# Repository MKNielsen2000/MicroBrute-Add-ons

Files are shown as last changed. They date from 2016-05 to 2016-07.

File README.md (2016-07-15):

#Microbrute addon boards / hacks
---

A bunch of boards for hacking / modifying the MicroBrute:
* White Noise Add-on
* Buffered output add-on

**DISCLAIMER: These hacks/modifications are potentially dangerous for you and/or your synth. They are only for people with advanced electronics skills. I will not take any responsibility for any damage to your synth or yourself and understand that once you open your MicroBrute you lose your warranty.**

## White Noise Add-on
A tiny board that adds white noise to the Microbrute. 

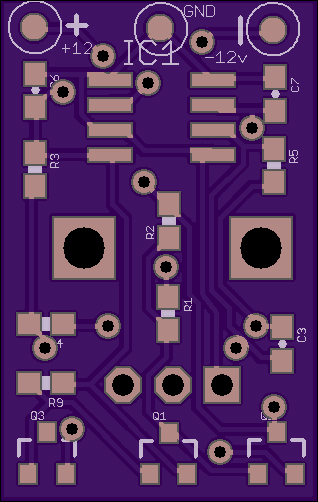
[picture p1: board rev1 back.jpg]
Back of board rev 1

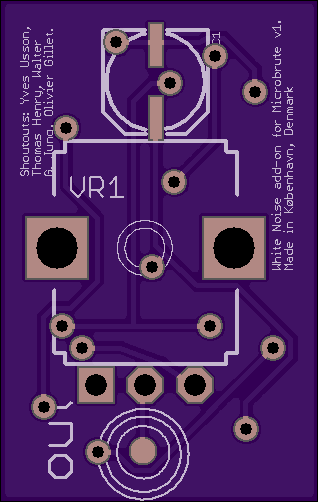
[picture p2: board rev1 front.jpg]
Front of board rev 1


Does what it says on the tin.

Based on a circuit from [Thomas Henry's noise generator cookbook](http://www.magsmoke.com/thomas_henry_books.asp).

Made possible thanks to [Yves Usson's publishing of all schematics related to the Microbrute.](http://hackabrute.yusynth.net/index_en.php)

#####STATUS
Boards done, need testing. 

####Connections

Power:
* Connect +12v to tp70 on the Microbrute
* Connect -12v to tp71 on the Microbrute
* Connect GND to tp72 on the Microbrute

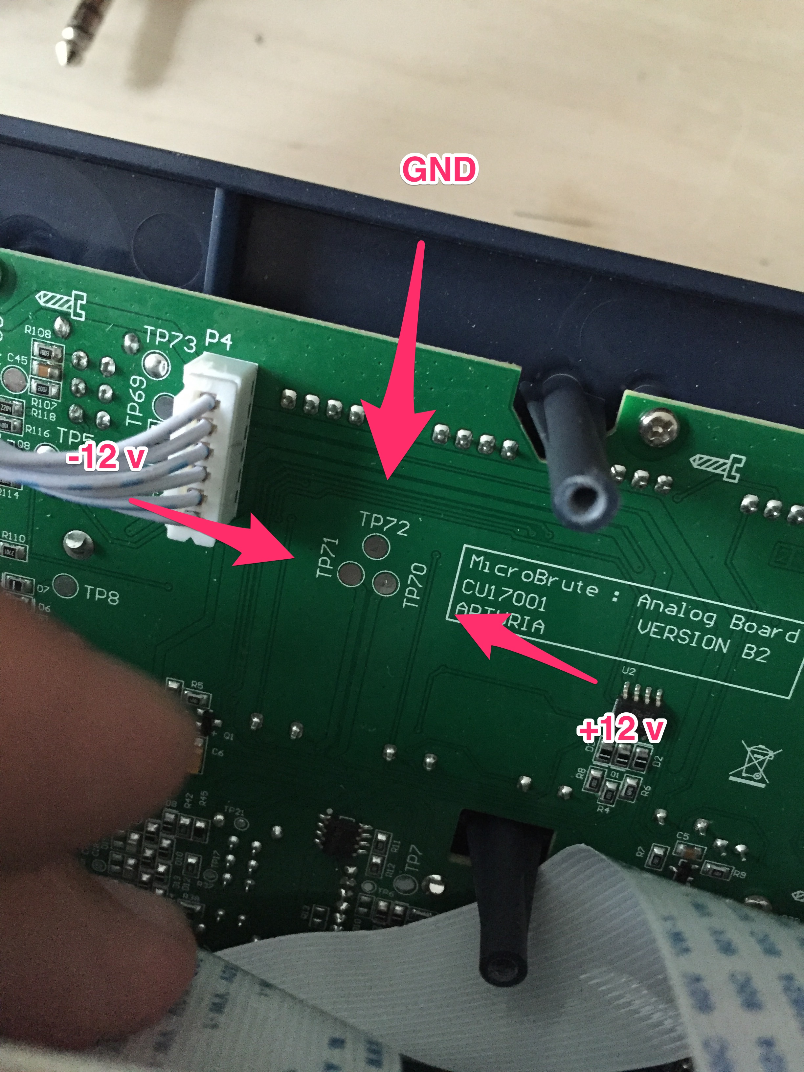
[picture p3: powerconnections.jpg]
power connections


White noise:
* Connect OUT on white noise board to tp47 (external audio in) on the Microbrute

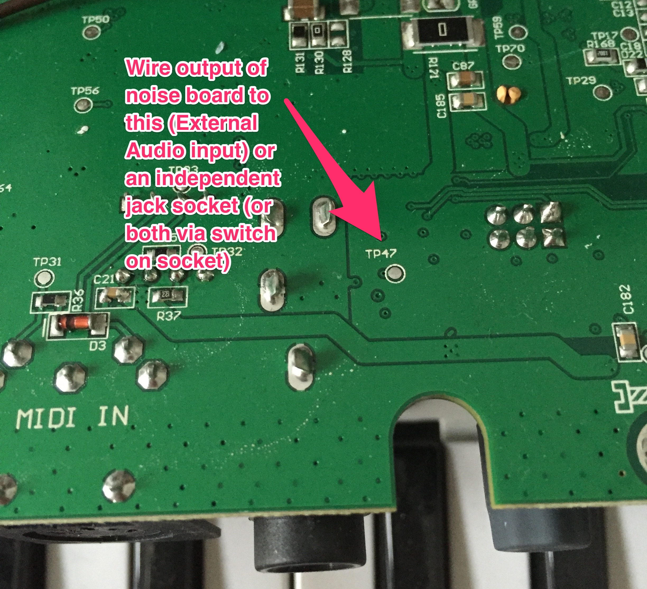
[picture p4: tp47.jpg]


## Buffered output Add-on
There are four waveform output hacks possible on the Microbrute but I've always thought it a damn shame that they get wired directly to output jacks with no protection and buffering which causes all sorts of issues. This boards fixes that problem. You mount this on one of the output jacks and wire three others to this board including the four waveforms. You can either pull the power from the above mentioned test points or daisy chain the power with the white noise generator. Pretty suave. 

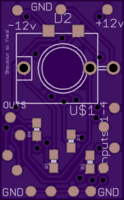
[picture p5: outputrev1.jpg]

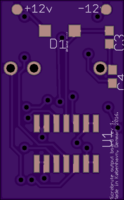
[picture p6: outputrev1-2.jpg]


#####STATUS
Boards done, need testing.

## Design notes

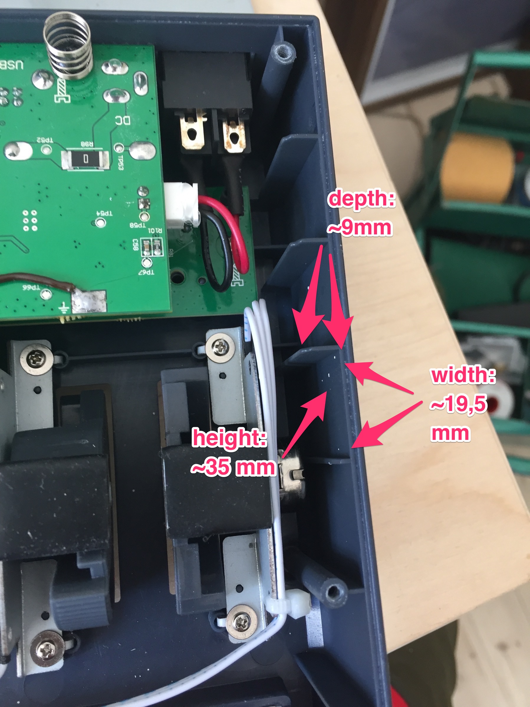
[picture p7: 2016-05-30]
Inner dimensions microbrute.jpg

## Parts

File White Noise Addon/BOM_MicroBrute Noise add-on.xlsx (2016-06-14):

Part | Value | Package | Description | PROD_ID | VALUE | Mouser
C1 | 10uf | PANASONIC_C | Capacitor Polarized |  |  | 667-EEE-FP1E100AR
C3 | 10pF | 0603-CAP | CAP-00810 | CAP-00810 |  | 81-GRM1885C1H102FA1J
C6 | 0.1uF | 0603-CAP | CAP-00810 | CAP-00810 | 0.1uF | 81-GRM188R61C104KA1D
C7 | 0.1uF | 0603-CAP | CAP-00810 | CAP-00810 | 0.1uF | 81-GRM188R61C104KA1D
IC1 | TL071D | SO08 | OP AMP |  |  | 511-TL071CDT
Q1 | mmbt3904 | SOT23-3 | Generic NPN BJT | TRANS-08049 |  | 863-MMBT3904LT1G
Q2 | mmbt3904 | SOT23-3 | Generic NPN BJT | TRANS-08049 |  | 863-MMBT3904LT1G
Q3 | mmbt3904 | SOT23-3 | Generic NPN BJT | TRANS-08049 |  | 863-MMBT3904LT1G
R1 | 47k | 0603-RES | Resistor |  |  | 667-ERJ-3EKF4702V
R2 | 10k | 0603-RES | Resistor |  |  | 667-ERJ3EKF1002V
R3 | 2.2k | 0603-RES | Resistor |  |  | 667-ERJ-3EKF2201V
R4 | 100k | 0603-RES | Resistor |  |  | 667-ERJ3EKF1003V
R5 | 100k | 0603-RES | Resistor |  |  | 667-ERJ3EKF1003V
R9 | 180k | 0603-RES | Resistor |  |  | 667-ERJ-3EKF1803V
VR1 | 100k | 9MM_SNAP-IN_POT | 9mm vertical snap-in pot, Alpha / Panasonic style |  |  | Buy at Thonk or Tayda
D1, D2 | Schottky diode PMEG2010AEB | SOD523 |  |  |  | 771-PMEG2010AEBT/R

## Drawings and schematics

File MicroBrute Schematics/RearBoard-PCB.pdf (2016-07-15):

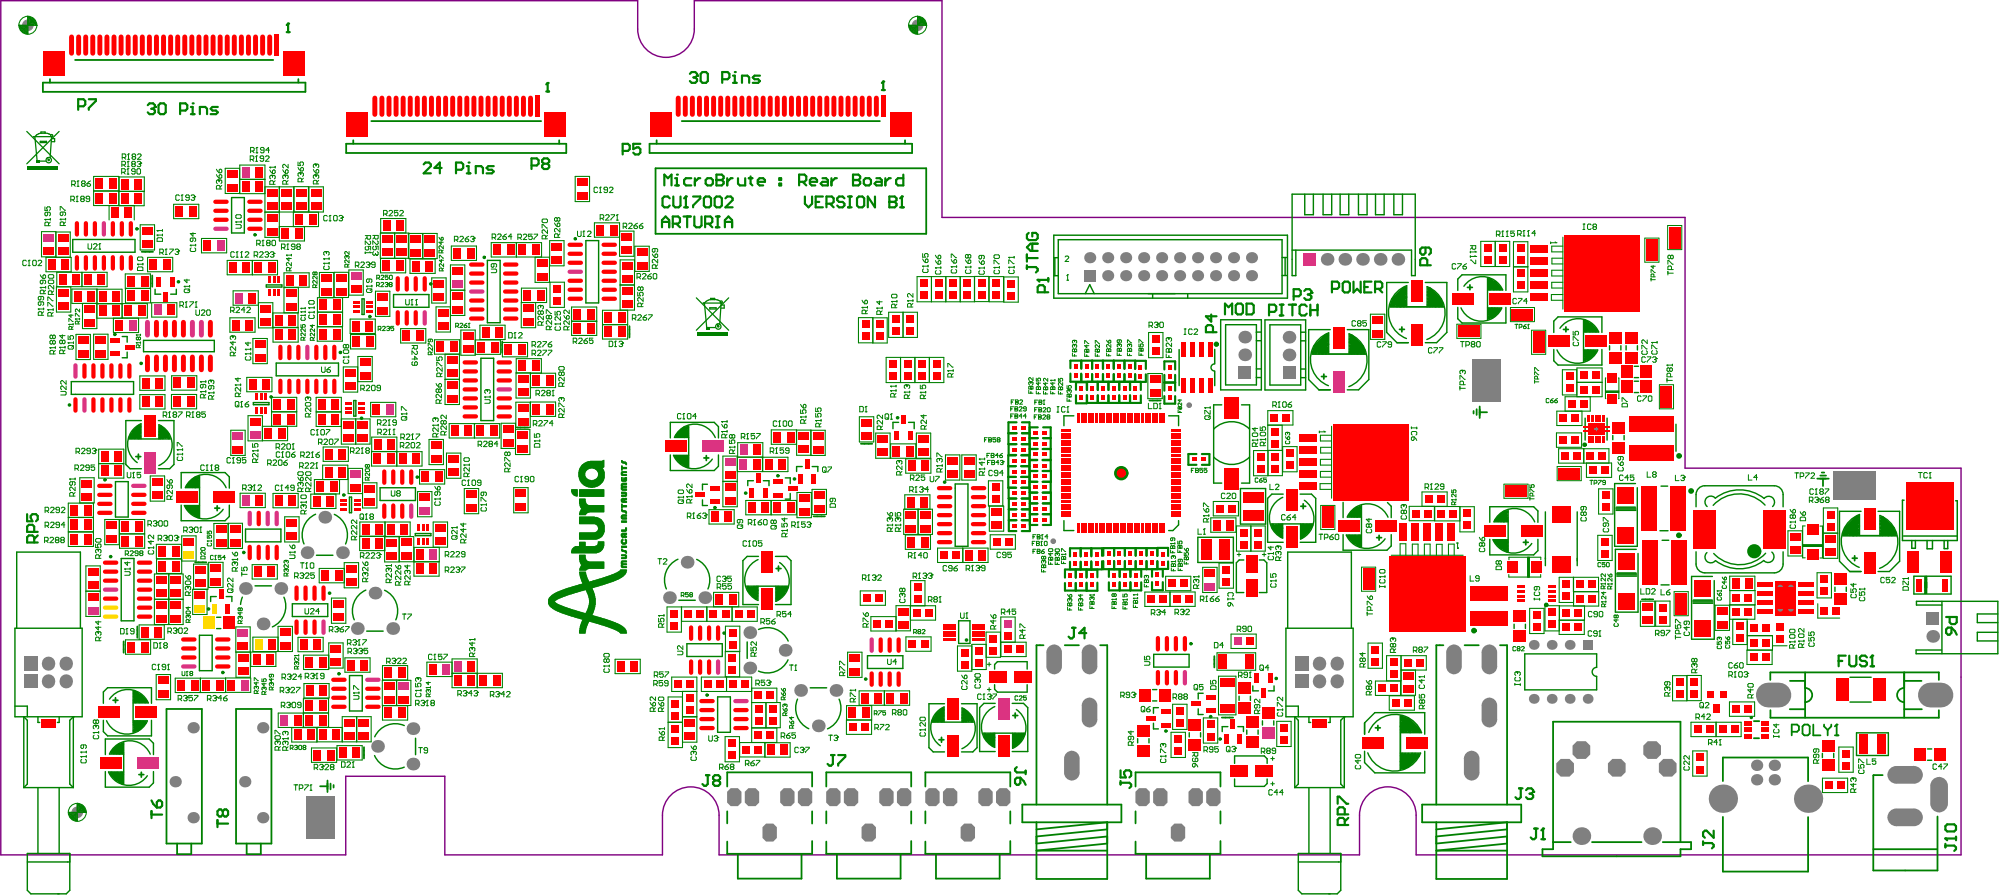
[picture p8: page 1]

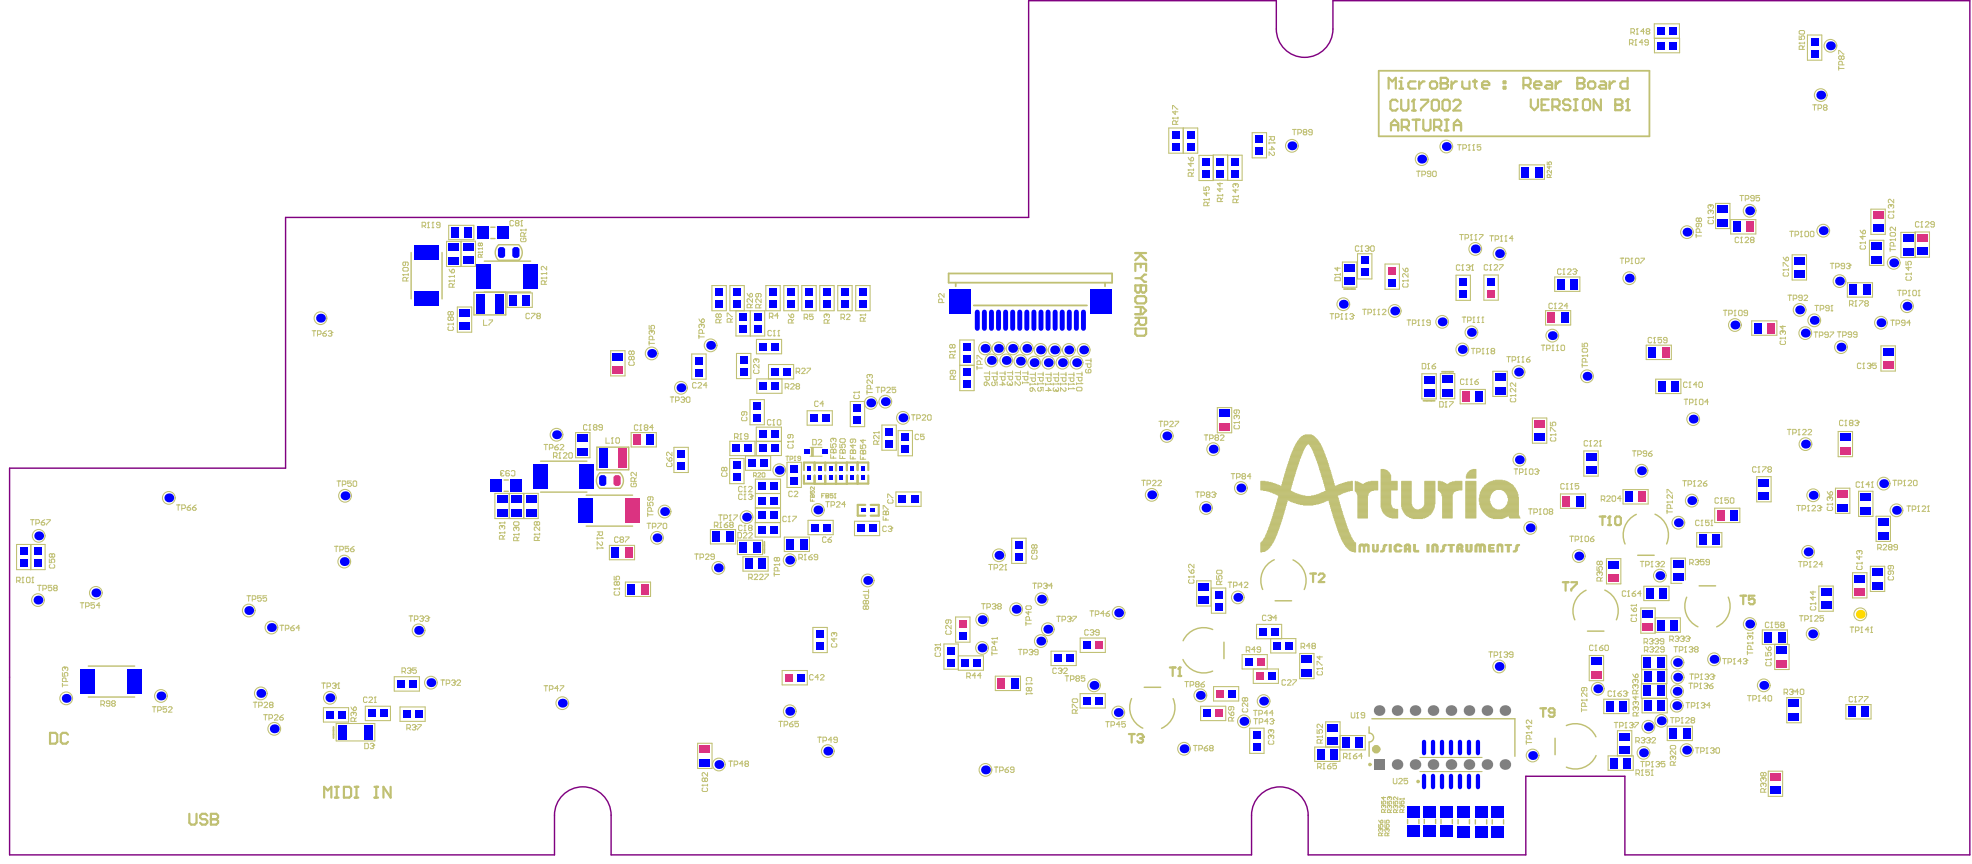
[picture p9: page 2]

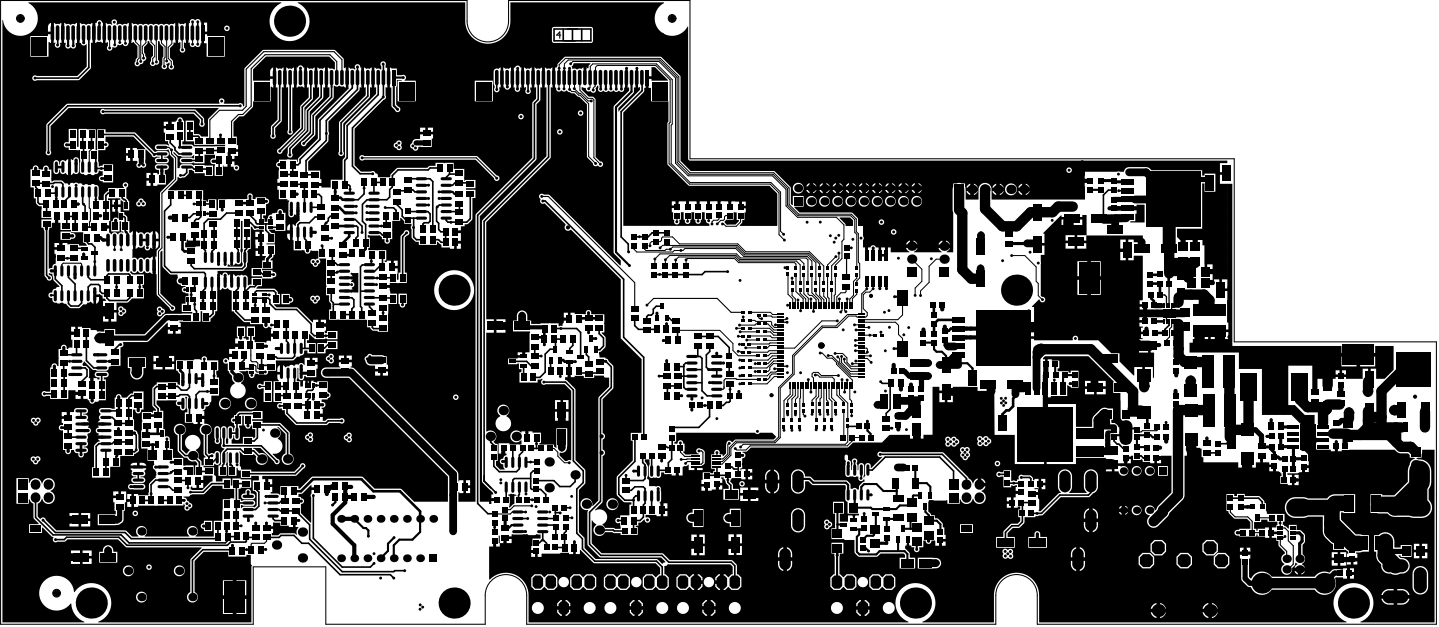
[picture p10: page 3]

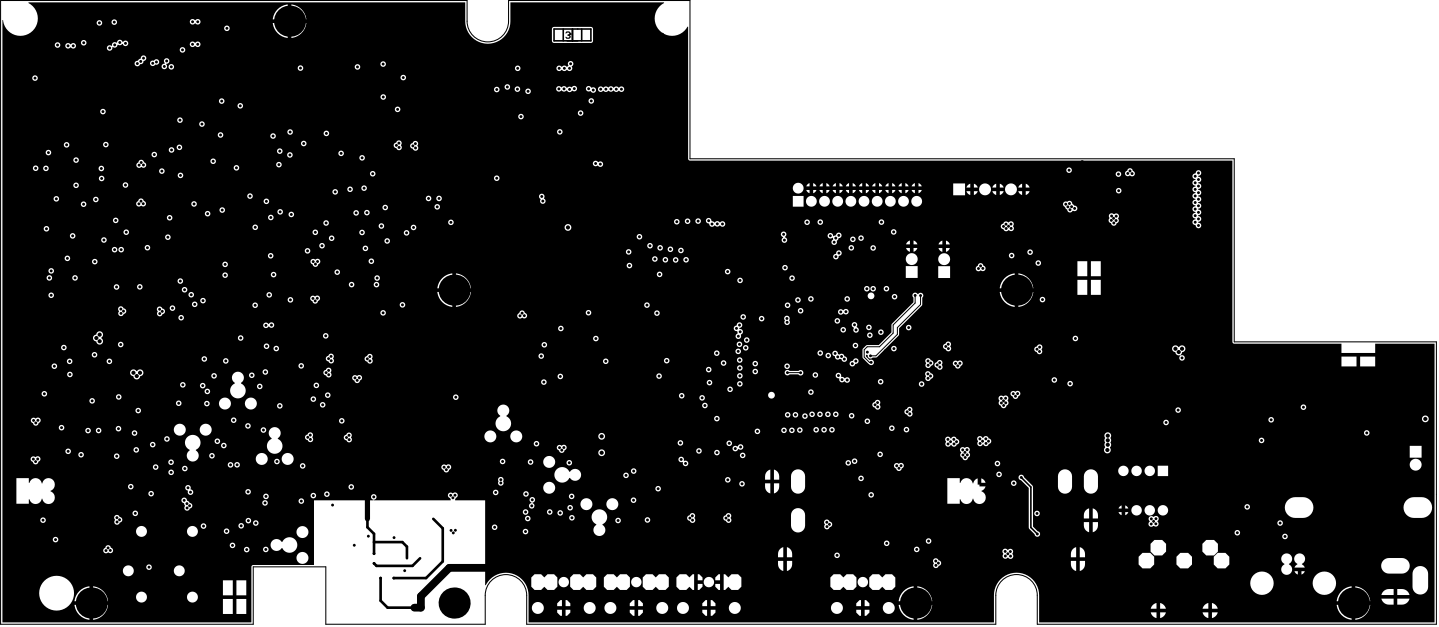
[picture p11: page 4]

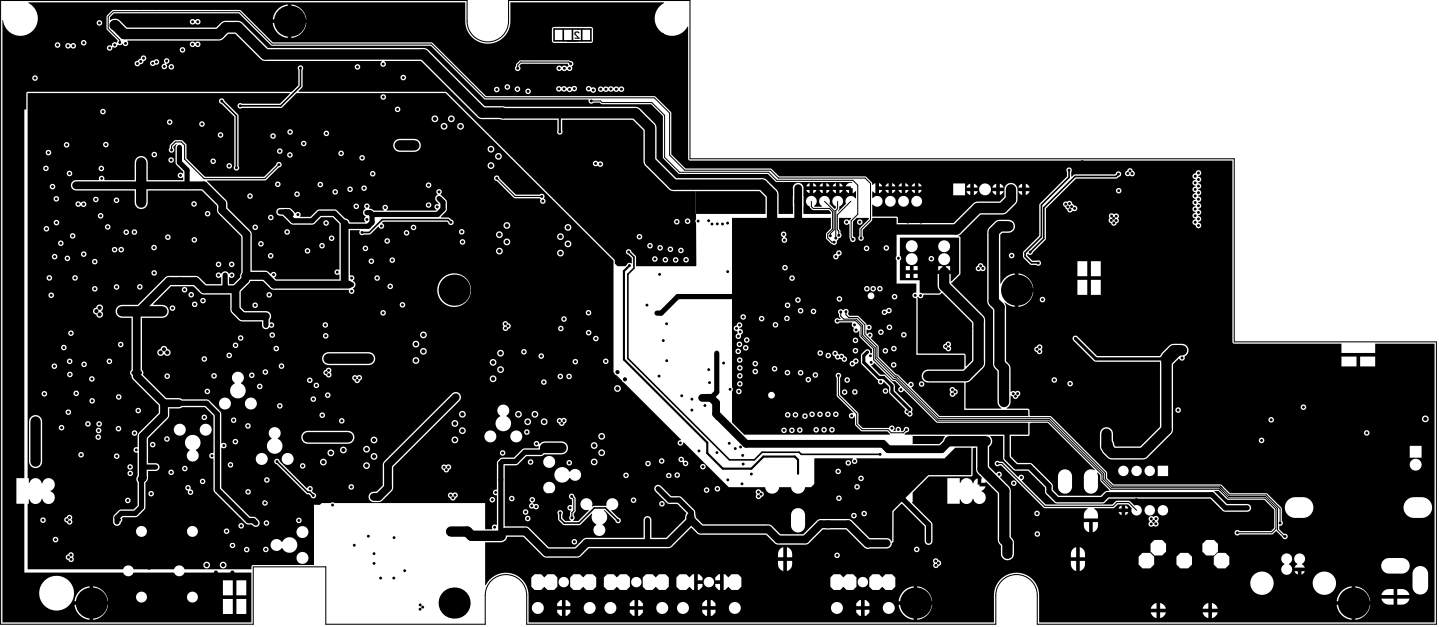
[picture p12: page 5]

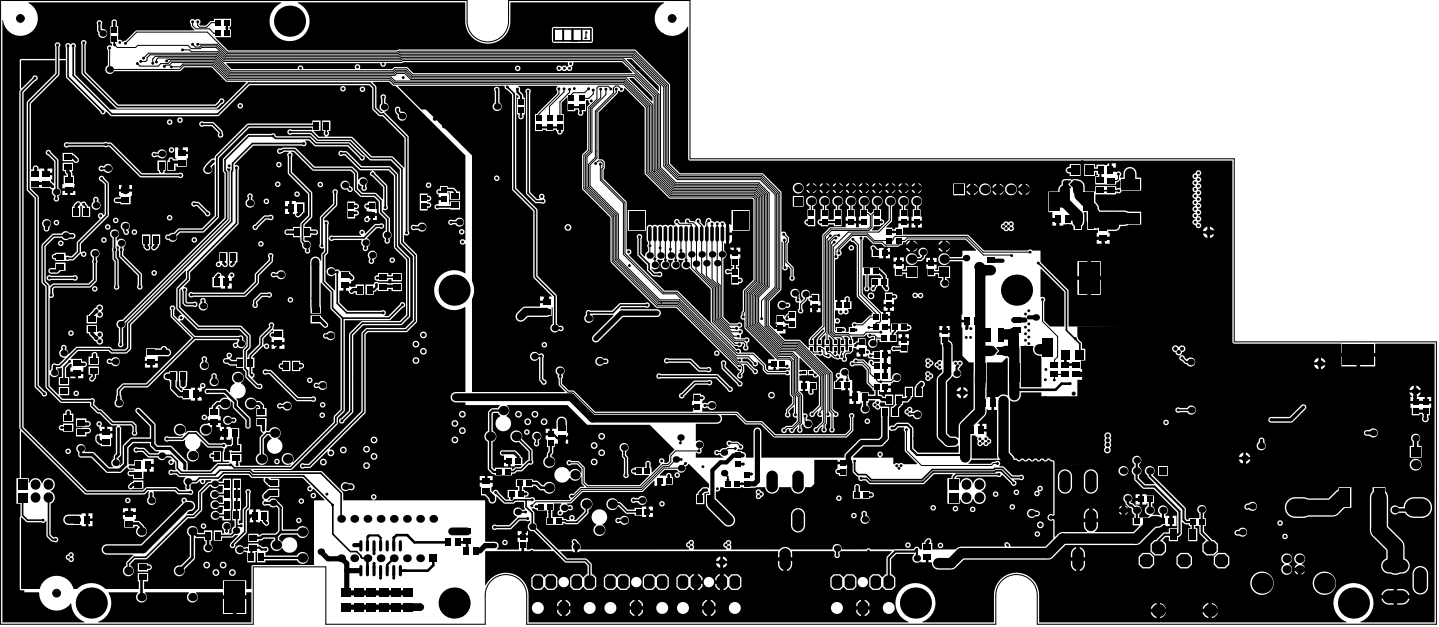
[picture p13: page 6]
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

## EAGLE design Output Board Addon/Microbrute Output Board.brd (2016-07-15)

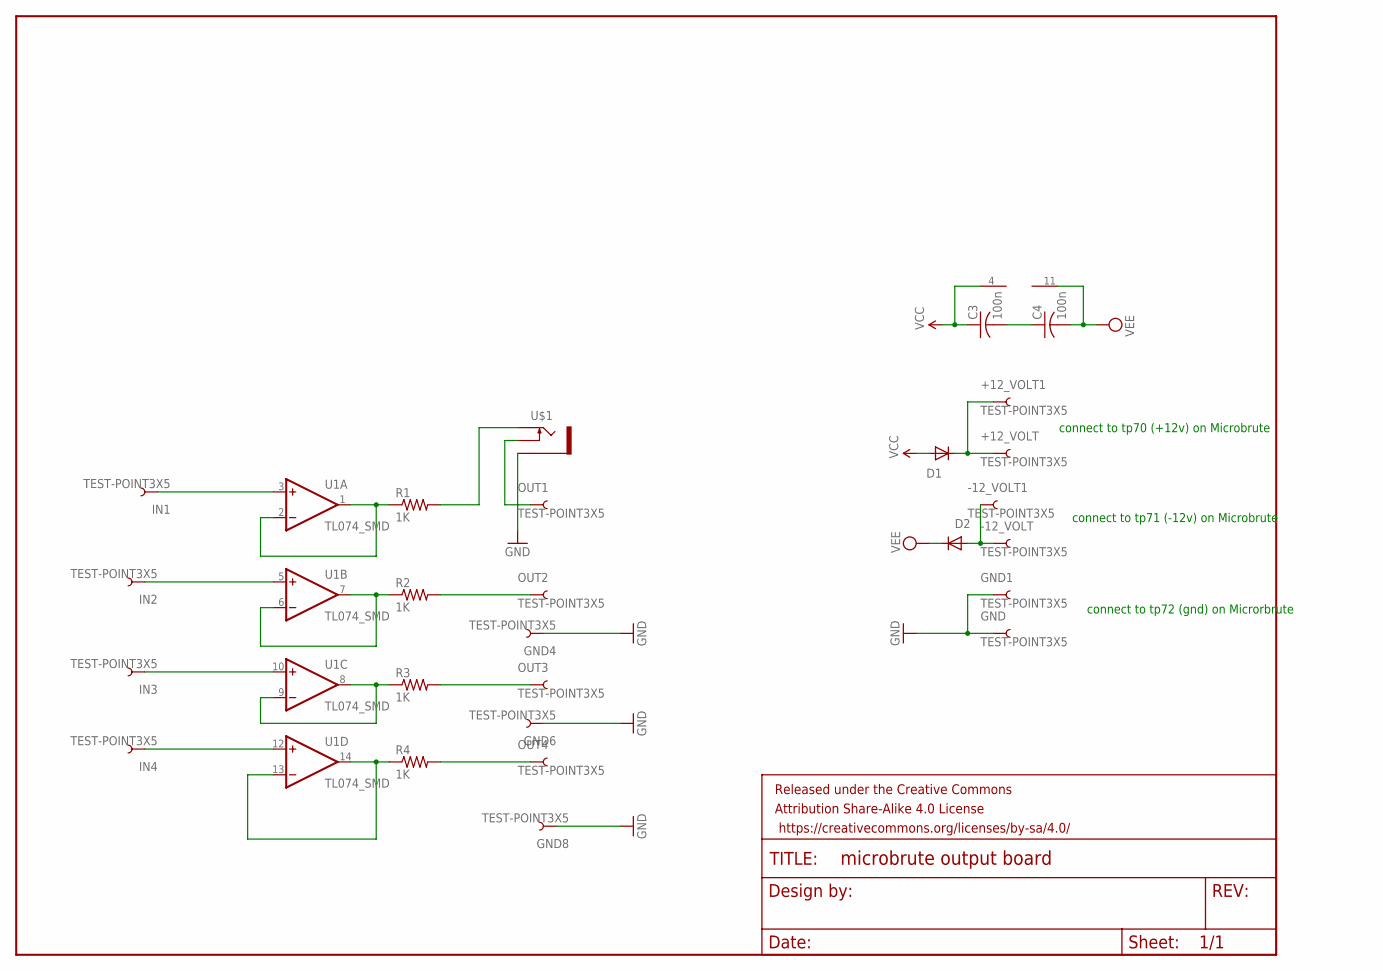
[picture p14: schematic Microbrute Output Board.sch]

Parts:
+12_VOLT, +12_VOLT1: TEST-POINT3X5; PAD.03X.05
-12_VOLT, -12_VOLT1: TEST-POINT3X5; PAD.03X.05
C3, C4: 100n; C0603
D1, D2: 1N5819HW; SOD123
FRAME1: FRAME-LETTER; CREATIVE_COMMONS
GND, GND1, GND4, GND6, GND8: TEST-POINT3X5; PAD.03X.05
IN1, IN2, IN3, IN4: TEST-POINT3X5; PAD.03X.05
OUT1, OUT2, OUT3, OUT4: TEST-POINT3X5; PAD.03X.05
R1, R2, R3, R4: 1K; 0603-RES
U1: TL074_SMD; SO14
U$1: THONKICONNNEW; WQP-PJ301M-12_JACK

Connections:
GND: GND.P$1, GND1.P$1, GND4.P$1, GND6.P$1, GND8.P$1, U$1.P$3_SLEEVE (SLEEVE)
GND1: C3.2, C4.1
unnamed: +12_VOLT.P$1, +12_VOLT1.P$1, D1.C
unnamed: -12_VOLT.P$1, -12_VOLT1.P$1, D2.A
unnamed: R1.2, U$1.P$1_TIP (TIP)
unnamed: OUT1.P$1, U$1.P$2_SWITCH (SWITCH)
unnamed: OUT2.P$1, R2.2
unnamed: R3.1, U1.8 (OUT), U1.9 (-IN)
unnamed: OUT4.P$1, R4.2
unnamed: R1.1, U1.1 (OUT), U1.2 (-IN)
unnamed: R2.1, U1.6 (-IN), U1.7 (OUT)
unnamed: OUT3.P$1, R3.2
unnamed: R4.1, U1.13 (-IN), U1.14 (OUT)
unnamed: IN2.P$1, U1.5 (+IN)
unnamed: IN3.P$1, U1.10 (+IN)
unnamed: IN4.P$1, U1.12 (+IN)
unnamed: IN1.P$1, U1.3 (+IN)
VCC: C3.1, D1.A, U1.4 (V+)
VEE: C4.2, D2.C, U1.11 (V-)

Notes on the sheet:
connect to tp70 (+12v) on Microbrute
connect to tp71 (-12v) on Microbrute
connect to tp72 (gnd) on Microrbrute

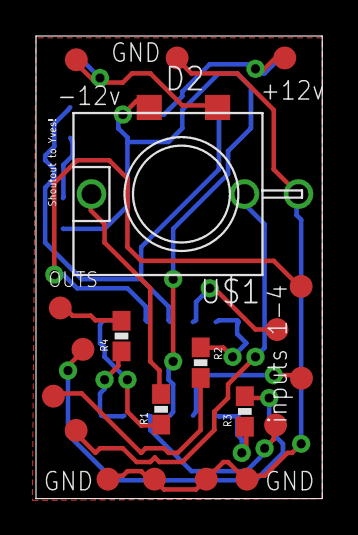
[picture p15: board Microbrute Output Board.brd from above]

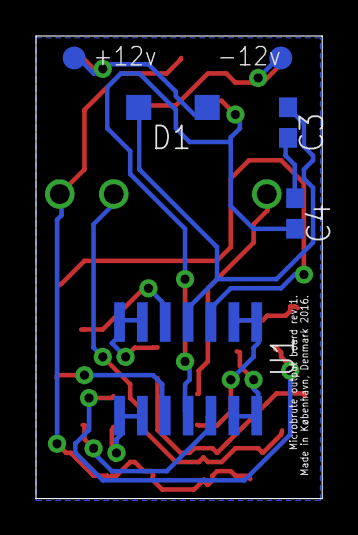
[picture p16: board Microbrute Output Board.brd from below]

Board: 2 copper layers, 15.9 x 25.7 mm, 28 parts (6 on the bottom side), 19 nets.

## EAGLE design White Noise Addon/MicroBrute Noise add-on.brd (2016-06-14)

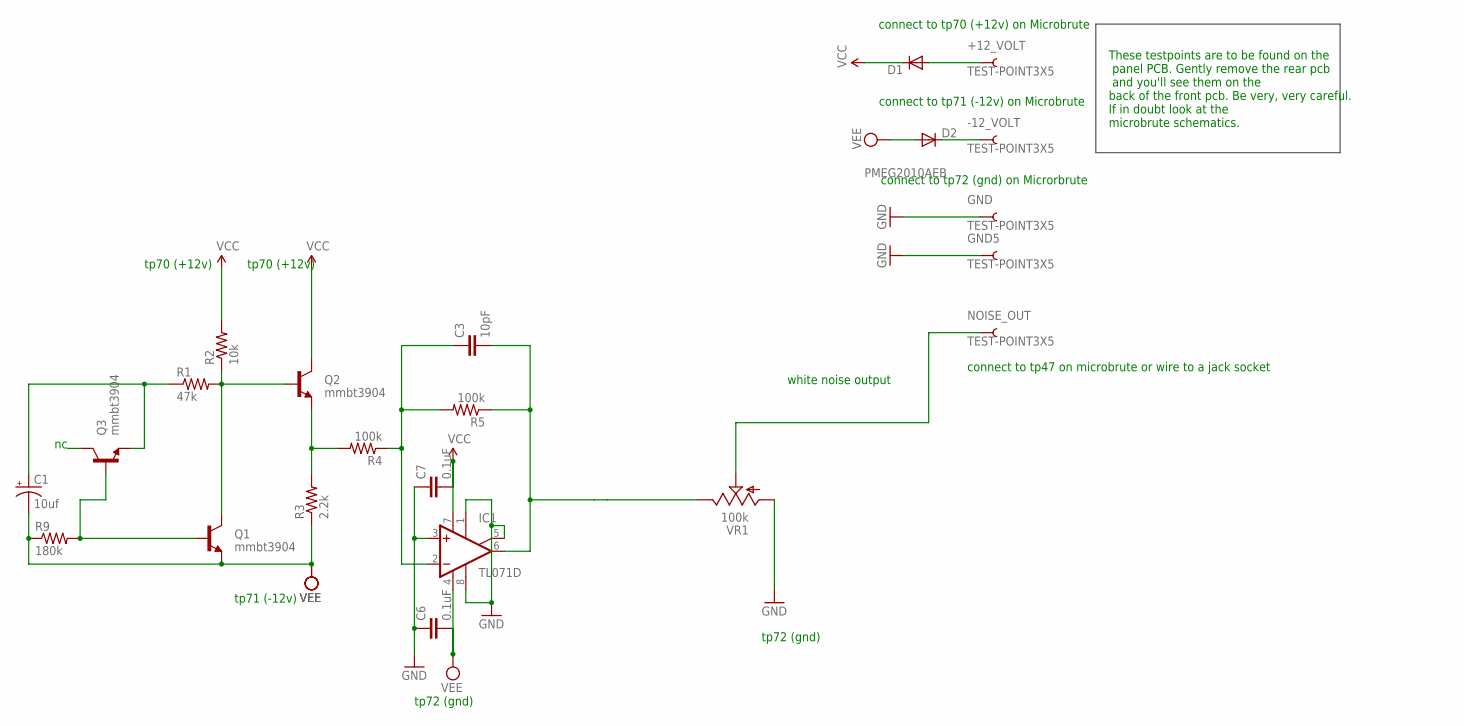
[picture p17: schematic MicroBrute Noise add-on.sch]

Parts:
+12_VOLT: TEST-POINT3X5; PAD.03X.05
-12_VOLT: TEST-POINT3X5; PAD.03X.05
C1: 10uf; PANASONIC_C
C3: 10pF; 0603-CAP
C6, C7: 0.1uF; 0603-CAP
D1, D2: PMEG2010AEB; SOD523
GND, GND5: TEST-POINT3X5; PAD.03X.05
IC1: TL071D; SO08
NOISE_OUT: TEST-POINT3X5; PAD.03X.05
Q1, Q2, Q3: mmbt3904; SOT23-3
R1: 47k; 0603-RES
R2: 10k; 0603-RES
R3: 2.2k; 0603-RES
R4, R5: 100k; 0603-RES
R9: 180k; 0603-RES
VR1: 100k; 9MM_SNAP-IN_POT

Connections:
GND: C6.1, C7.1, GND.P$1, GND5.P$1, IC1.1 (ON1), IC1.3 (+IN), IC1.5 (ON2), IC1.8 (OPT), VR1.1 (A)
unnamed: Q1.1 (B), Q3.1 (B), R9.2
unnamed: C1.+, Q3.2 (E), R1.1
unnamed: Q2.2 (E), R3.2, R4.2
unnamed: C3.2, IC1.6 (OUT), R5.1, VR1.3 (E)
unnamed: +12_VOLT.P$1, D1.A
unnamed: C3.1, IC1.2 (-IN), R4.1, R5.2
unnamed: -12_VOLT.P$1, D2.C
unnamed: Q1.3 (C), Q2.1 (B), R1.2, R2.1
unnamed: NOISE_OUT.P$1, VR1.2 (S)
VCC: C7.2, D1.C, IC1.7 (V+), Q2.3 (C), R2.2
VEE: C1.-, C6.2, D2.A, IC1.4 (V-), Q1.2 (E), R3.1, R9.1

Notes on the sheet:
tp71 (-12v)
tp70 (+12v)
tp72 (gnd)
white noise output
connect to tp70 (+12v) on Microbrute
connect to tp71 (-12v) on Microbrute
connect to tp72 (gnd) on Microrbrute
connect to tp47 on microbrute or wire to a jack socket
These testpoints are to be found on the panel PCB. Gently remove the rear pcb and you'll see them on the back of the front pcb. Be very, very careful. If in doubt look at the microbrute schematics.

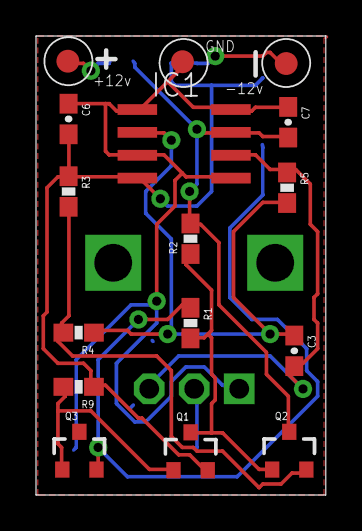
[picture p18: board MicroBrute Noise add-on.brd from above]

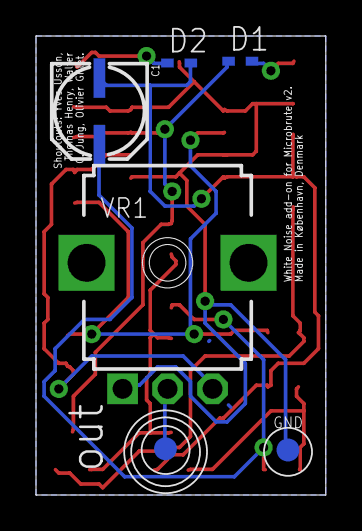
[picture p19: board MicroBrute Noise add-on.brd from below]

Board: 2 copper layers, 16.1 x 25.5 mm, 22 parts (6 on the bottom side), 12 nets.

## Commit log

2016-05-30 update for oshpark
    [MicroBrute Noise add-on.brd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]
2016-05-30 bom upload
    [BOM_MicroBrute Noise add-on.csv]
2016-06-14 Added diodes to pcb, uploaded BOM
    [BOM_MicroBrute Noise add-on.csv, BOM_MicroBrute Noise add-on.xlsx, MicroBrute Noise add-on.brd]
2016-06-14 added pic of power connections
2016-06-14 added image of tp47
    [MicroBrute Noise add-on.brd]
2016-06-14 Finished output board
    [Microbrute Output Board.brd, Microbrute Output Board.sch]
2016-07-15 Fixed vital problem: Orientation of power diodes was wrong
    [Microbrute Output Board.brd, Microbrute Output Board.sch]

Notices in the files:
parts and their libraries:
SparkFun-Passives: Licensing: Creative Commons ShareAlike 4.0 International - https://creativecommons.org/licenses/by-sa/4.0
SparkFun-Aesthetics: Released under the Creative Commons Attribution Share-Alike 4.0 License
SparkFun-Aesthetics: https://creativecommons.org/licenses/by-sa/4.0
